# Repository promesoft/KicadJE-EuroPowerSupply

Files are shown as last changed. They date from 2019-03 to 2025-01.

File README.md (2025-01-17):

# KicadJE-EuroPowerSupply
Takes a Laptop 19V input and makes +-12 and 5 v out

Please note there is a followup to this repo that has half the width and some fixes: https://github.com/promesoft/KicadJE-EuroPowerSupply2
Please note this method of making +- 12v could be impaired by the laptop PSU ground connection. Some PSU's connect earth to GND (sleeve) which will be connected to -12v and not GND in this circuit.

# MK1 Design
## Status - Installed in Rack
## Initial Unit
| Stage  | Detail | Status |
| --- | --- | --- |
| create material  | sch/pcb | done  |
| | gerber | done |
| production  | | done |
|  | produced | Done |
|  | delivered | Done |
## Preliminary validation
| Test  | Detail | Status |
| --- | --- | --- |
| Initial Inspection |  | OK |
| Initial Technical Test | | OK see errata |
| Initial Product Test | | OK |

## Secondary validation
| Test  | Detail | Status |
| --- | --- |--- |
| Product Test |  | OK |
| Quality |  | |
| Long Term Product Test | | Installed in rack  - extended to "EuroPowerCon" via +-13,5v |
| |  | Working fine after 1 year with different modules coming and going |

## Second Unit tests
| Test  | Action | Status |
| --- | --- |--- |
| Lower Power Consumption | Bypass Line regulation TIP41 and turn down DCDC to 27v |  |
| Lower Power Consumption | twist the offset of VGND in favor of a Vss = -14v Vcc = -13v |  |
| Simplify | Ommit Banana Jacks | |

## Errata
 * U203 DCDC 5V stepdn converter mirrored pinout - mount on other side (where there is more room)
 * Smaller +28V DCDC does not work - they burn themselves (tried 3 units)
## Issues and Notes
Note - as most powerdraw is on the +12V and +5V side the negative rail is not pulling down the VGND and the TIP42 needs to do all the heavy lifting - resulting in wasting almost 1/2 the power in this transistor.

The TIP41 line regulator passes all the current and the more regulation it needs to perform the more power it wastes and the hotter it gets. Therefore the Zener input should be matched well with the DCDC Boosted output to avoid power wastage.

Another result is a higher Current draw on the primary side, which will blow the input fuse faster. As a result - a powerdraw of 200mA on +12v will result in almost 0,5A on the primary side.

 * Bananas cant be mounted on PCB - too short
 * Consider soft startup current
 * Consider larger drill size for 7812 7805 and 7912
 * Consider cooling of TIP41's and TIP42
 * Blue LED is brighter than RED - Consider 1k for RED +12 470R for RED +5 and 1k5 for BLUE 
### Workarounds
 * U203 DCDC 5V stepdn converter mirrored pinout - mount on other side (where there is more room - and easier adjustment options)

# Base Construction 
The idea is to have a laptop power supply provide the power for the synth, as they are powerful and inexpensive.
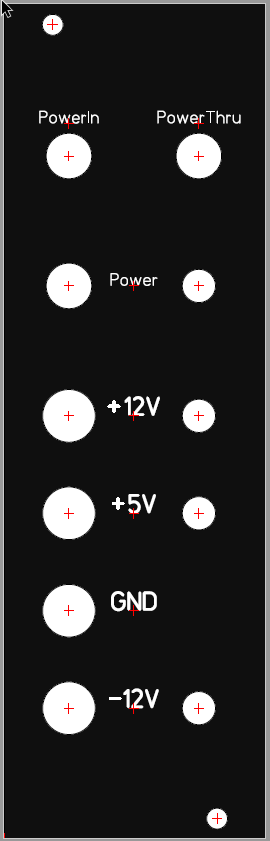
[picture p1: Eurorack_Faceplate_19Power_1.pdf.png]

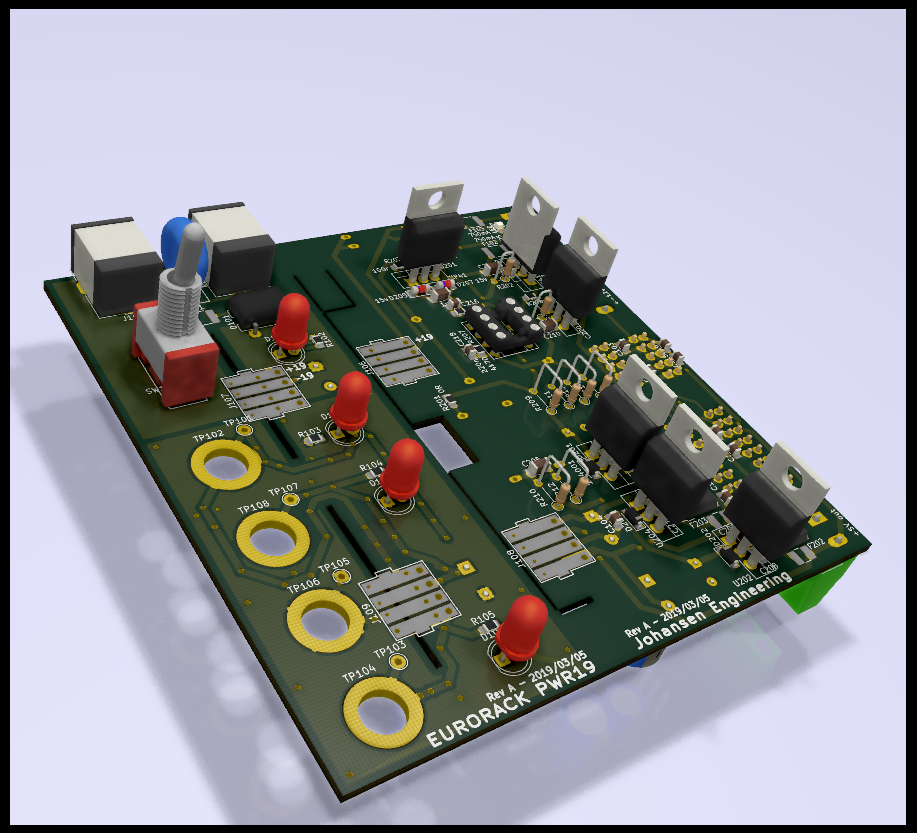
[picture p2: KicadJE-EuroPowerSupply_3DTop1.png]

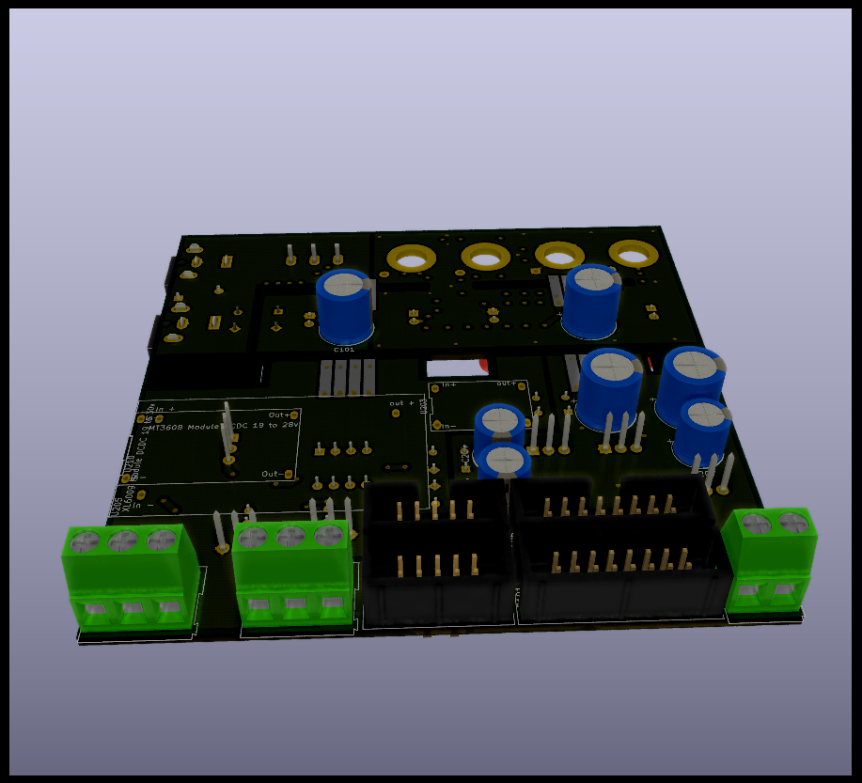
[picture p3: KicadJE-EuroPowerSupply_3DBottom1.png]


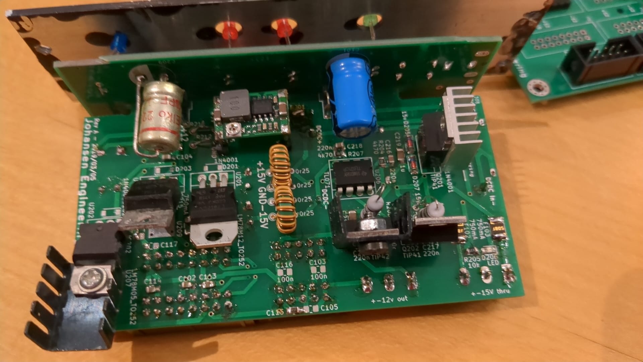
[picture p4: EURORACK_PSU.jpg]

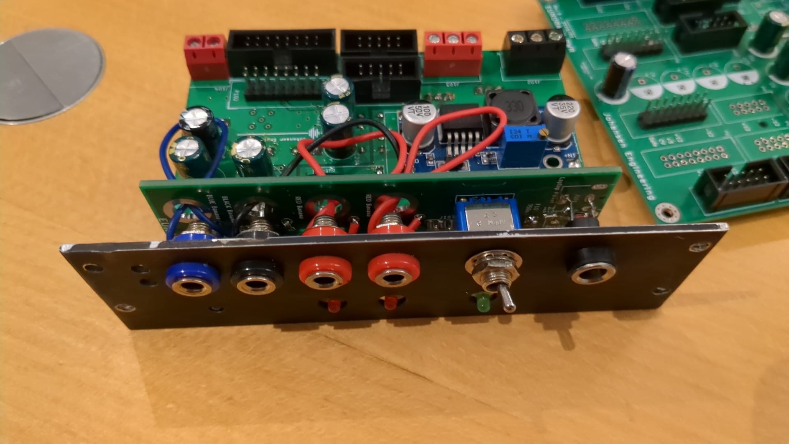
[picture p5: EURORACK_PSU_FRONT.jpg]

## Inputs
19v DC barrel jack.

## Outputs
### Front side
 - Banana +12v
 - Banana +5v
 - Banana GND
 - Banana -12v

### Back side
 - 10 pin doepfer connector
 - 16 pin doepfer connector
 - +/- 12v connector
 - +5 v connector

## Electrical
The input is fed to a DC-DC boost converter (to 30volts) and to a virtual GND circuit (making it +-15v) for the +-12v supply.
The +15v is sent to a step down converter (to 7volts) for the +5v supply.
The +-15 and +7 volt supplies are provided through common mode chokes to linear regulators.

## Regulation and noise 
### Input
No filtering on the input except for the overvoltage protection and  smoothing capacitor after the bridge rectifier.
### DCDC - Boost 30v
Directly on the DCDC output is made room for a Zener regulated NPN for 28 or 30v depending on the boost converter.
The 30v is sent to a Virtual GND that has smoothing capacitors on the input and output.
After the VGND room has been made for either small resistors (forming an RC filter) or a common mode choke for high frequency filtering.
Regulation is performed after the RC / LC filter with linear 7812 / 7912 regulators.

### DCDC - Buck 5v

### Safety / Protection
The 19v is fed through a bridge rectifier to protect the circuit and allow for both AC and DC with any polarity. The circuit is protected on the input by a polyfuse and a VDR afterwards in parallel with a Zener (or TVS) in series w a small resistor to protect from overcurrent, over voltage and spikes.
The linear regulators are fused with polyfuses

## Physical
The product is an 8HP module for the front of a Eurorack synth.

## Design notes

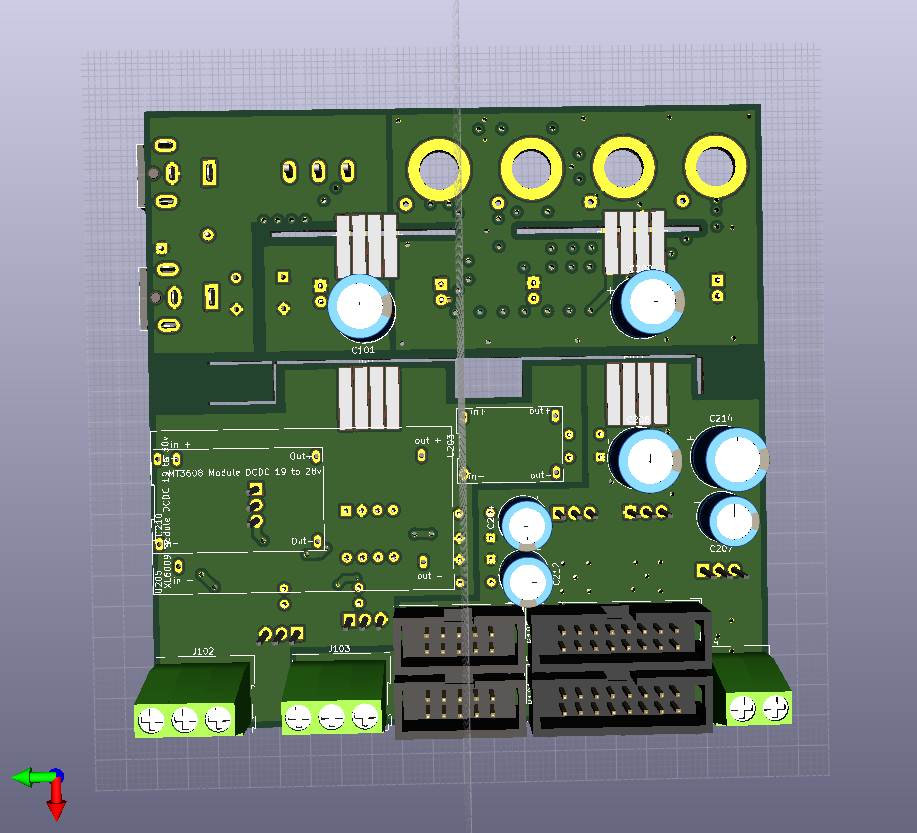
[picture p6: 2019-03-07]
KicadJE-EuroPowerSupply_3DBottom2.png

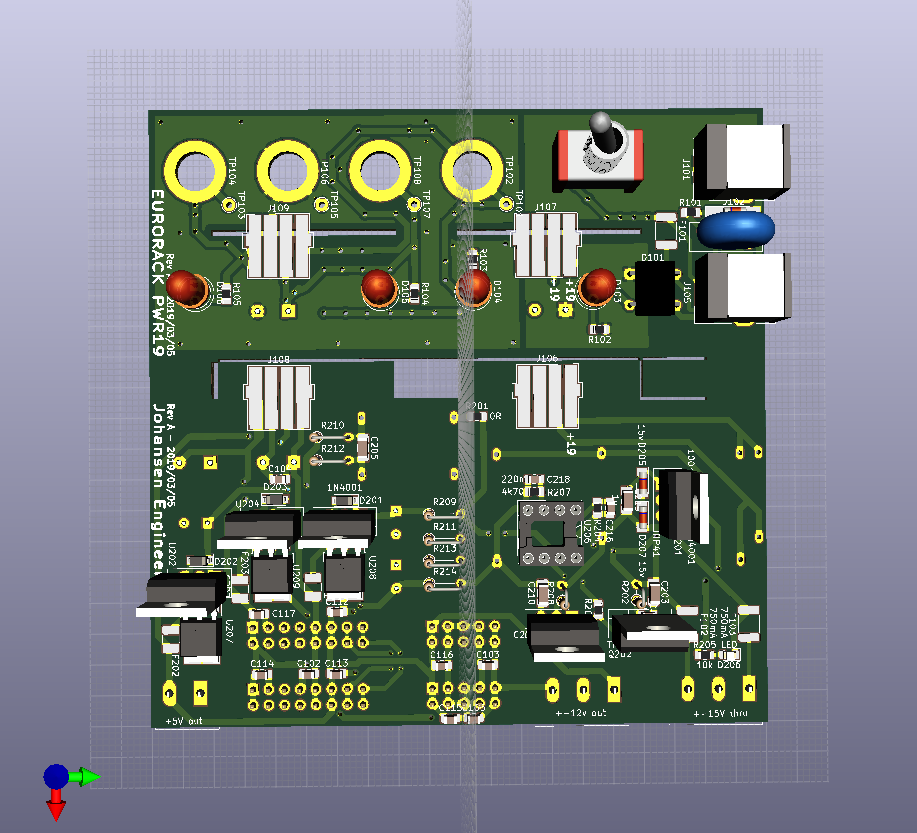
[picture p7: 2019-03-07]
KicadJE-EuroPowerSupply_3DTop2.png

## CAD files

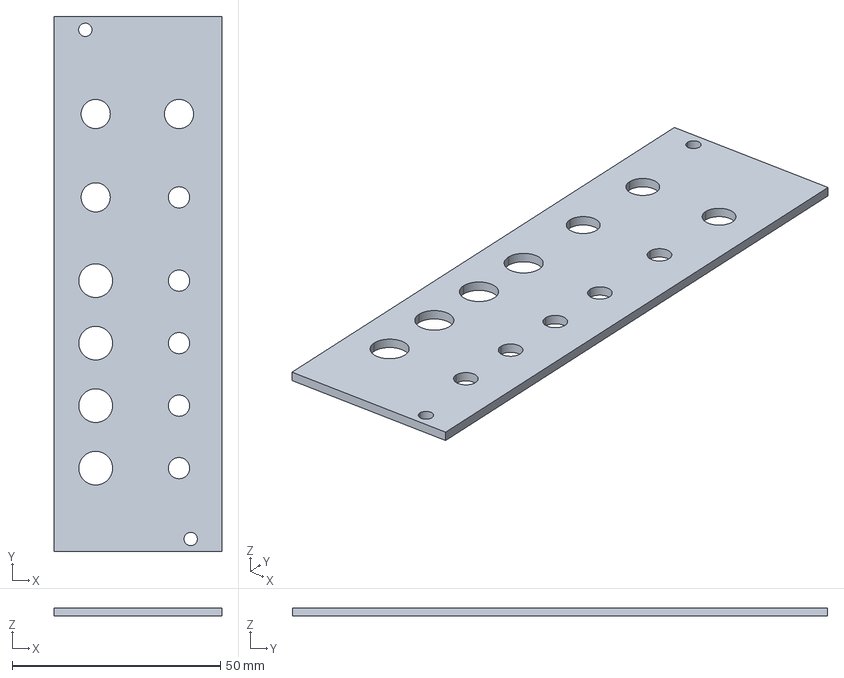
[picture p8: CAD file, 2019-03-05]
Eurorack_Faceplate_19Power_1.stp
40.3 x 128.4 x 2.00 mm

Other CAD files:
Eurorack_Faceplate_19Power_1.dxf

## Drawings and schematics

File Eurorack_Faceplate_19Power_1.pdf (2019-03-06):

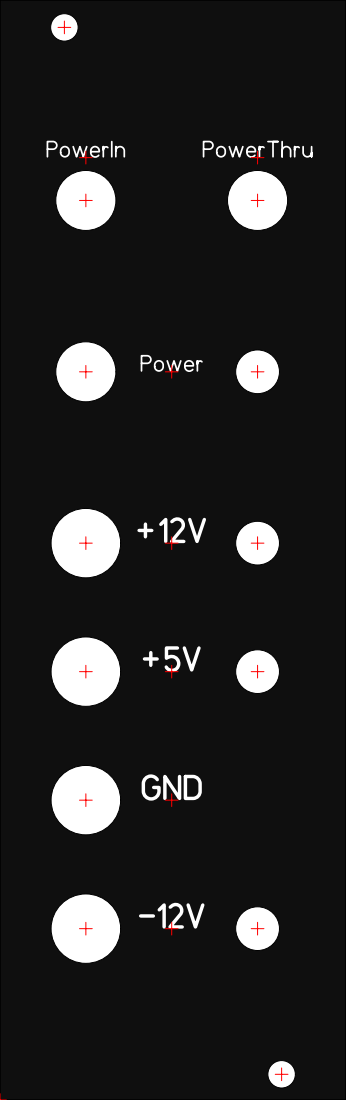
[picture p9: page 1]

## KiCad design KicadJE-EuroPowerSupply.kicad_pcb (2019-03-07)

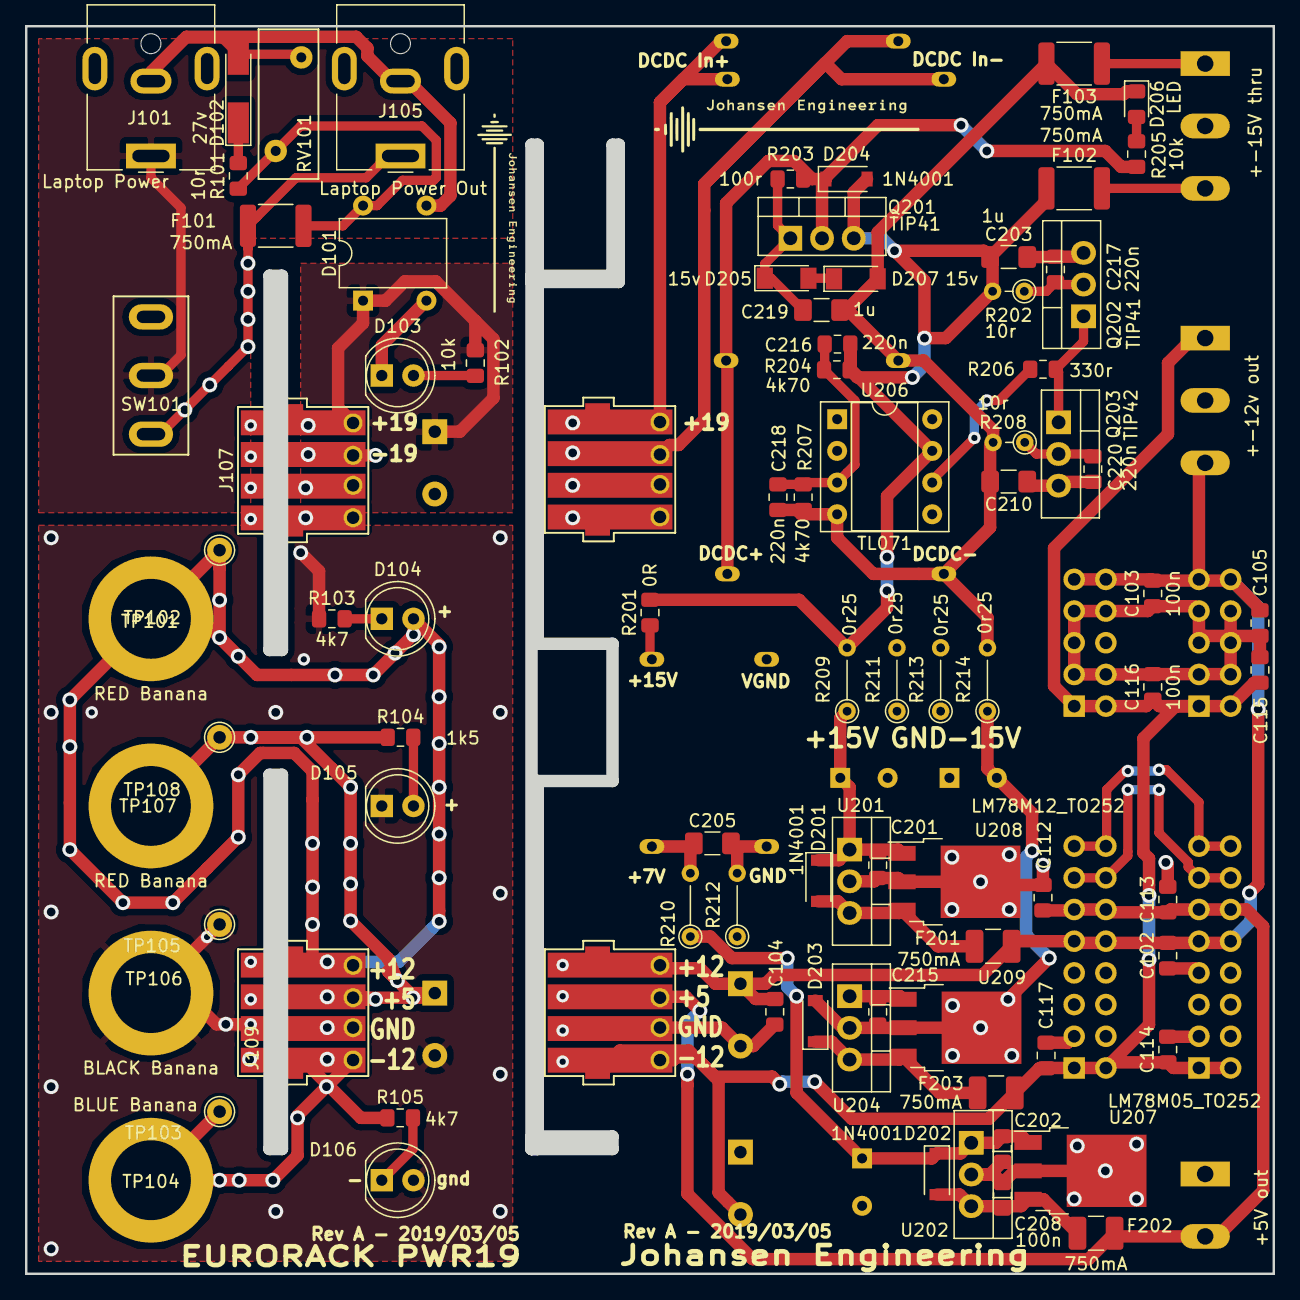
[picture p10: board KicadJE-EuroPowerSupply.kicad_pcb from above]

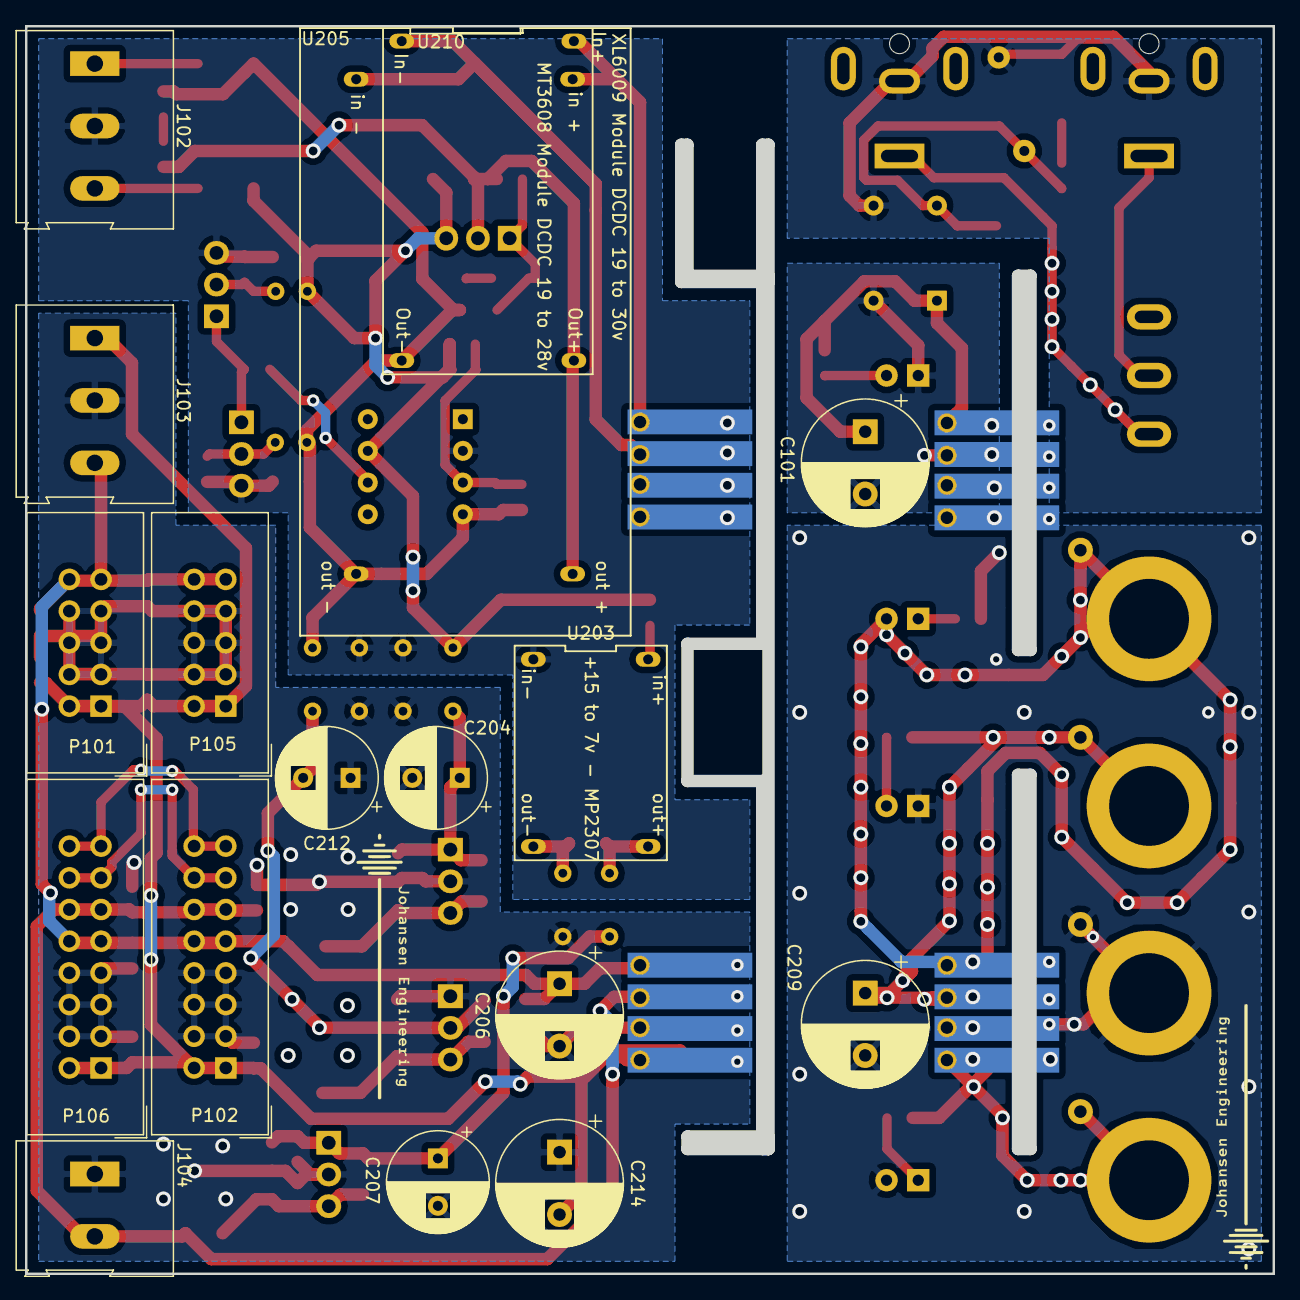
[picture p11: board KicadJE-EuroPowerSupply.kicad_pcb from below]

Board: 2 copper layers, 100.0 x 100.0 mm, 103 parts (17 on the bottom side), 40 nets.

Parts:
C101: 100uF; CP_Radial_D10.0mm_P5.00mm
C102, C103, C104, C105, C112, C113, C114, C115, C116, C117, C201, C202, C208, C215: 100n; C_0805_2012Metric_Pad1.15x1.40mm_HandSolder
C203, C205, C210, C219: 1u; C_1206_3216Metric_Pad1.42x1.75mm_HandSolder
C204, C207, C212: 1000uF; CP_Radial_D8.0mm_P3.80mm
C206, C209, C214: 1000uF; CP_Radial_D10.0mm_P5.00mm
C216, C217, C218, C220: 220n; C_0805_2012Metric_Pad1.15x1.40mm_HandSolder
D101: B125C800DM - DB107; Diode_Bridge_DIP-4_W7.62mm_P5.08mm
D102: 27v; D_MiniMELF_Handsoldering
D103: PWR_IN_LED; LED_D5.0mm
D104, D105, D106: LED; LED_D5.0mm
D201, D202, D203, D204: 1N4001; D_SOD-123
D205, D207: 15v; D_MiniMELF
D206: LED; LED_0805_2012Metric_Pad1.15x1.40mm_HandSolder
F101, F102, F103: 750mA; Fuse_1812_4532Metric_Pad1.30x3.40mm_HandSolder
F201, F202, F203: 750mA; Fuse_1210_3225Metric_Pad1.42x2.65mm_HandSolder
J101: Laptop Power; BarrelJack_CUI_PJ-063AH_Horizontal
J102: +-15V thru; TerminalBlock_Altech_AK300-3_P5.00mm
J103: +-12v out; TerminalBlock_Altech_AK300-3_P5.00mm
J104: +5V out; TerminalBlock_Altech_AK300-2_P5.00mm
J105: Laptop Power Out; BarrelJack_CUI_PJ-063AH_Horizontal
J106: FrontInterConnVin; BoardConnector2x2.54x10mm4pin
J107: BaseInterConnVin; BoardConnector2x2.54x10mm4pin
J108: FrontInterConnVout; BoardConnector2x2.54x10mm4pin
J109: BaseInterConnVout; BoardConnector2x2.54x10mm4pin
P101, P105: Doepfer_Power_10pin; IDC-Header_2x05_Pitch2.54mm_Straight
P102, P106: Doepfer_Power_16pin; IDC-Header_2x08_Pitch2.54mm_Straight
Q201, Q202: TIP41; TO-220-3_Vertical
Q203: TIP42; TO-220-3_Vertical
R101: 10r; R_0805_2012Metric_Pad1.15x1.40mm_HandSolder
R102, R205: 10k; R_0805_2012Metric_Pad1.15x1.40mm_HandSolder
R103, R105: 4k7; R_0805_2012Metric_Pad1.15x1.40mm_HandSolder
R104: 1k5; R_0805_2012Metric_Pad1.15x1.40mm_HandSolder
R201: 0R; R_0805_2012Metric_Pad1.15x1.40mm_HandSolder
R202, R208: 10r; R_Axial_DIN0204_L3.6mm_D1.6mm_P2.54mm_Vertical
R203: 100r; R_0805_2012Metric_Pad1.15x1.40mm_HandSolder
R204, R207: 4k70; R_0805_2012Metric_Pad1.15x1.40mm_HandSolder
R206: 330r; R_0805_2012Metric_Pad1.15x1.40mm_HandSolder
R209, R210, R211, R212, R213, R214: 0r25; R_Axial_DIN0204_L3.6mm_D1.6mm_P5.08mm_Vertical
RV101: Varistor; RV_Disc_D12mm_W4.8mm_P7.5mm
SW101: SW_SPDT; SP1MS1
TP101, TP107: RED Sleeve; TestPoint_THTPad_D2.0mm_Drill1.0mm
TP102, TP108: RED Banana; MountingHole_6.4mm_M6_ISO14580_Pad
TP103: BLUE Sleeve; TestPoint_THTPad_D2.0mm_Drill1.0mm
TP104: BLUE Banana; MountingHole_6.4mm_M6_ISO14580_Pad
TP105: BLACK Sleeve; TestPoint_THTPad_D2.0mm_Drill1.0mm
TP106: BLACK Banana; MountingHole_6.4mm_M6_ISO14580_Pad
U201: LM7812_TO220; TO-220-3_Vertical
U202: LM7805_TO220; TO-220-3_Vertical
U203: +15 to 7v - MP2307; MP2307 DCDC module
U204: LM7912_TO220; TO-220-3_Vertical
U205: XL6009 Module DCDC 19 to 30v; XL6009-DCDC-Module
U206: TL071; DIP-8_W7.62mm_Socket
U207: LM78M05_TO252; TO-252-3_TabPin2
U208: LM78M12_TO252; TO-252-3_TabPin2
U209: MC79M12_TO252; TO-252-3_TabPin2
U210: MT3608 Module DCDC 19 to 28v; MT3608 DCDC-Module-USB

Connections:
5Vreg: C208.1, D202.2, F202.1, U202.3, U207.3
12Vreg: D201.2, F201.1, U201.3, U208.3
+5V: C112.1, C113.1, C209.1, F202.2, J104.2, J108.2, J109.2, P102.11, P102.12, P106.11, P106.12, R104.1, TP107.1, TP108.1
+7.5V: C202.1, C207.1, D202.1, R210.1, U202.1, U207.1
+12V: C102.2, C103.2, C104.2, C105.2, C206.1, D104.2, F201.2, J103.3, J108.1, J109.1, P101.9, P101.10, P102.9, P102.10, P105.9, P105.10, P106.9, P106.10, TP101.1, TP102.1
+15V: C201.1, C204.1, D201.1, R209.1, U201.1, U208.1
-12V: C114.1, C115.1, C116.1, C117.1, C214.2, F203.2, J103.1, J108.4, J109.4, P101.1, P101.2, P102.1, P102.2, P105.1, P105.2, P106.1, P106.2, R105.1, TP103.1, TP104.1
-12Vreg: D203.1, F203.1, U204.3, U209.3
-15V: C212.2, C215.2, D203.2, R214.1, U204.2, U209.2
/DCSleeve: D101.3, D102.2, J101.2, J105.2, RV101.2
/VoltageRegulation/7V: C205.1, R210.2, U203.4
/VoltageRegulation/GND-7V: C205.2, R212.2, U203.3
CV: P102.13, P102.14, P106.13, P106.14
DCDC+: D204.1, Q201.2, R203.1, R205.1, U205.4, U210.4
GND: C102.1, C103.1, C104.1, C105.1, C112.2, C113.2, C114.2, C115.2, C116.2, C117.2, C201.2, C202.2, C204.2, C206.2, C207.2, C208.2, C209.2, C212.1, C214.1, C215.1, D105.1, D106.2, J103.2, J104.1, J108.3, J109.3, P101.3, P101.4, P101.5, P101.6, P101.7, P101.8, P102.3, P102.4, P102.5, P102.6, P102.7, P102.8, P105.3, P105.4, P105.5, P105.6, P105.7, P105.8, P106.3, P106.4, P106.5, P106.6, P106.7, P106.8, R103.1, R211.1, R212.1, R213.1, TP105.1, TP106.1, U201.2, U202.2, U204.1, U207.2, U208.2, U209.1
Gate: P102.15, P102.16, P106.15, P106.16
unnamed: C216.2, C218.1, R204.2, R207.1, U206.3
unnamed: C217.1, Q202.2, R202.1
unnamed: C219.1, D205.1, Q201.1, R203.2
unnamed: C220.2, Q203.2, R208.1
unnamed: D101.4, F101.2, R101.1, RV101.1
unnamed: D102.1, R101.2
unnamed: D103.2, R102.2
unnamed: D104.1, R103.2
unnamed: D105.2, R104.2
unnamed: D106.1, R105.2
unnamed: D205.2, D207.1
unnamed: D206.2, R205.2
unnamed: F101.1, J105.1, SW101.1
unnamed: F102.2, J102.3
unnamed: F103.1, J102.1
unnamed: J101.1, SW101.2
unnamed: Q202.1, Q203.1, R206.1
unnamed: R201.1, U203.2
unnamed: R206.2, U206.6
Vin+15: C203.1, C216.1, D204.2, F102.1, Q201.3, R201.2, R202.2, R204.1, R209.2, U206.7
Vin-15: C210.2, C218.2, C219.2, D206.1, D207.2, F103.2, R207.2, R208.2, R214.2, U205.3, U206.4, U210.3
Vin-Neg19: C101.2, D101.2, D103.1, J106.2, J107.2, U205.1, U210.1
Vin-Pos19: C101.1, D101.1, J106.1, J107.1, R102.1, U205.2, U210.2
VinGND: C203.2, C210.1, C217.2, C220.1, J102.2, Q202.3, Q203.3, R211.2, R213.2, U203.1, U206.2

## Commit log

2019-03-04 schematics taking shape
    [KicadJE-EuroPowerSupply.kicad_pcb, KicadJE-EuroPowerSupply.sch]
2019-03-05 schematic break up in two sheets
    [KicadJE-EuroPowerSupply.sch, VoltageRegulation.sch]
2019-03-05 Linear regulation on 30V DCDC with BJT
    [KicadJE-EuroPowerSupply.sch, VoltageRegulation.sch]
2019-03-05 alternative DCDC and replaced XL4005 w XL6009
    [KicadJE-EuroPowerSupply.sch, VoltageRegulation.sch]
2019-03-05 Barel jacks footprints
    [KicadJE-EuroPowerSupply.kicad_pcb, KicadJE-EuroPowerSupply.sch, VoltageRegulation.sch]
2019-03-05 Front Plate and DXF file created - DXF file imported in PCB
    [Eurorack_Faceplate_19Power_1.dxf, Eurorack_Faceplate_19Power_1.stp, KicadJE-EuroPowerSupply.kicad_pcb]
2019-03-05 cut down to 2x10p and 2x16p
    [KicadJE-EuroPowerSupply.kicad_pcb, KicadJE-EuroPowerSupply.sch]
2019-03-05 Toroid footprints
    [VoltageRegulation.sch]
2019-03-05 TO252 output fused
    [VoltageRegulation.sch]
2019-03-05 3D Jigzaw started 90degr
    [KicadJE-EuroPowerSupply.kicad_pcb, VoltageRegulation.sch]
2019-03-06 Board interconnect
    [KicadJE-EuroPowerSupply.sch]
2019-03-06 Init wiring
    [KicadJE-EuroPowerSupply.kicad_pcb, KicadJE-EuroPowerSupply.sch]
2019-03-07 Components placed on PCB - common modes removed
    [KicadJE-EuroPowerSupply.kicad_pcb, VoltageRegulation.sch]
2019-03-07 TP removed - common modes replaced by low ohm resistors
    [VoltageRegulation.sch]
2019-03-07 Initial Route
    [KicadJE-EuroPowerSupply.kicad_pcb, _saved_KicadJE-EuroPowerSupply.sch]
2019-03-07 3D png
    [VoltageRegulation.sch, _saved_KicadJE-EuroPowerSupply.sch]
2019-03-07 faceplate text
    [KicadJE-EuroPowerSupply.kicad_pcb]
2019-03-13 Noise filtering
2019-04-03 Update README.md
    Power talks
2025-01-16 Update README.md
    https://github.com/promesoft/KicadJE-EuroPowerSupply2
2025-01-16 Update README.md
    Please note this method of making +- 12v could be impaired by the laptop PSU ground connection. Some PSU's connect earth to GND (sleeve) which will be connected to -12v and not GND in this circuit.
2025-01-17 Pictures of the completed pcb
